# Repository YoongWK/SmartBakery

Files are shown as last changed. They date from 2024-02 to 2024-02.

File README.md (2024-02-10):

# Smart Bakery

The Smart Bakery system is a comprehensive solution for monitoring and controlling temperature and humidity within a bakery. Using a Raspberry Pi Model 3B with a BME280 module, the system publishes data from the bakery to a Flask server via MQTT for storage in an InfluxDB V3.0 Cloud Serverless database. Users can view the bakery data via a Web Dashboard created using HTML, CSS, and JavaScript.

The dashboard also allows users to set temperature thresholds, control heating (Bulb) and cooling (Fan) devices, and activate/deactivate a buzzer alert for extreme temperatures. Moreover, an RGB LED provides a clear visual indication of the current operational status for floor managers in the bakery. Additionally, the system can operate automatically where fan speed and bulb heat levels are adjusted according to the current temperature or manually for direct user control.

By providing real-time environmental tracking and responsive control, the system can maintain optimal conditions in the bakery for high-quality baked goods.

<br />

## Instructions for Raspberry Pi Model 3B Setup
> Step 1: Fabricate the PCB using the gerber files in EAGLE\PCB\SmartBakerySensor

> Step 2: Assemble the PCB

> Step 3: Connect the PCB to the Raspberry Pi Model 3B

> Step 4: Run the Smart_Bakery_Sensor.py Python script in the the Raspberry Pi Model 3B

<br />

## Instructions for Dashboard Setup
> Step 1: Download the app

```bash
git clone https://github.com/YoongWK/SmartBakery.git
cd SmartBakery
```

> Step 2: Enter your MQTT & InfluxDB V3.0 Cloud Serverless details in the .env.example file

> Step 3: Rename the .env.example file to .env

> Step 4: Create the Python virtual environment

```bash
python -m venv .venv
```

> Step 5: Set the execution policy of the current user to unrestricted

```bash
Set-ExecutionPolicy -ExecutionPolicy Unrestricted  -Scope CurrentUser
```

> Step 6: Activate the virtual environment

```bash
.venv\Scripts\activate
```

> Step 7: Install the required libraries into the virtual environment

```bash
pip install -r requirements.txt
```

> Step 8: Run the app

```bash
python app.py
```

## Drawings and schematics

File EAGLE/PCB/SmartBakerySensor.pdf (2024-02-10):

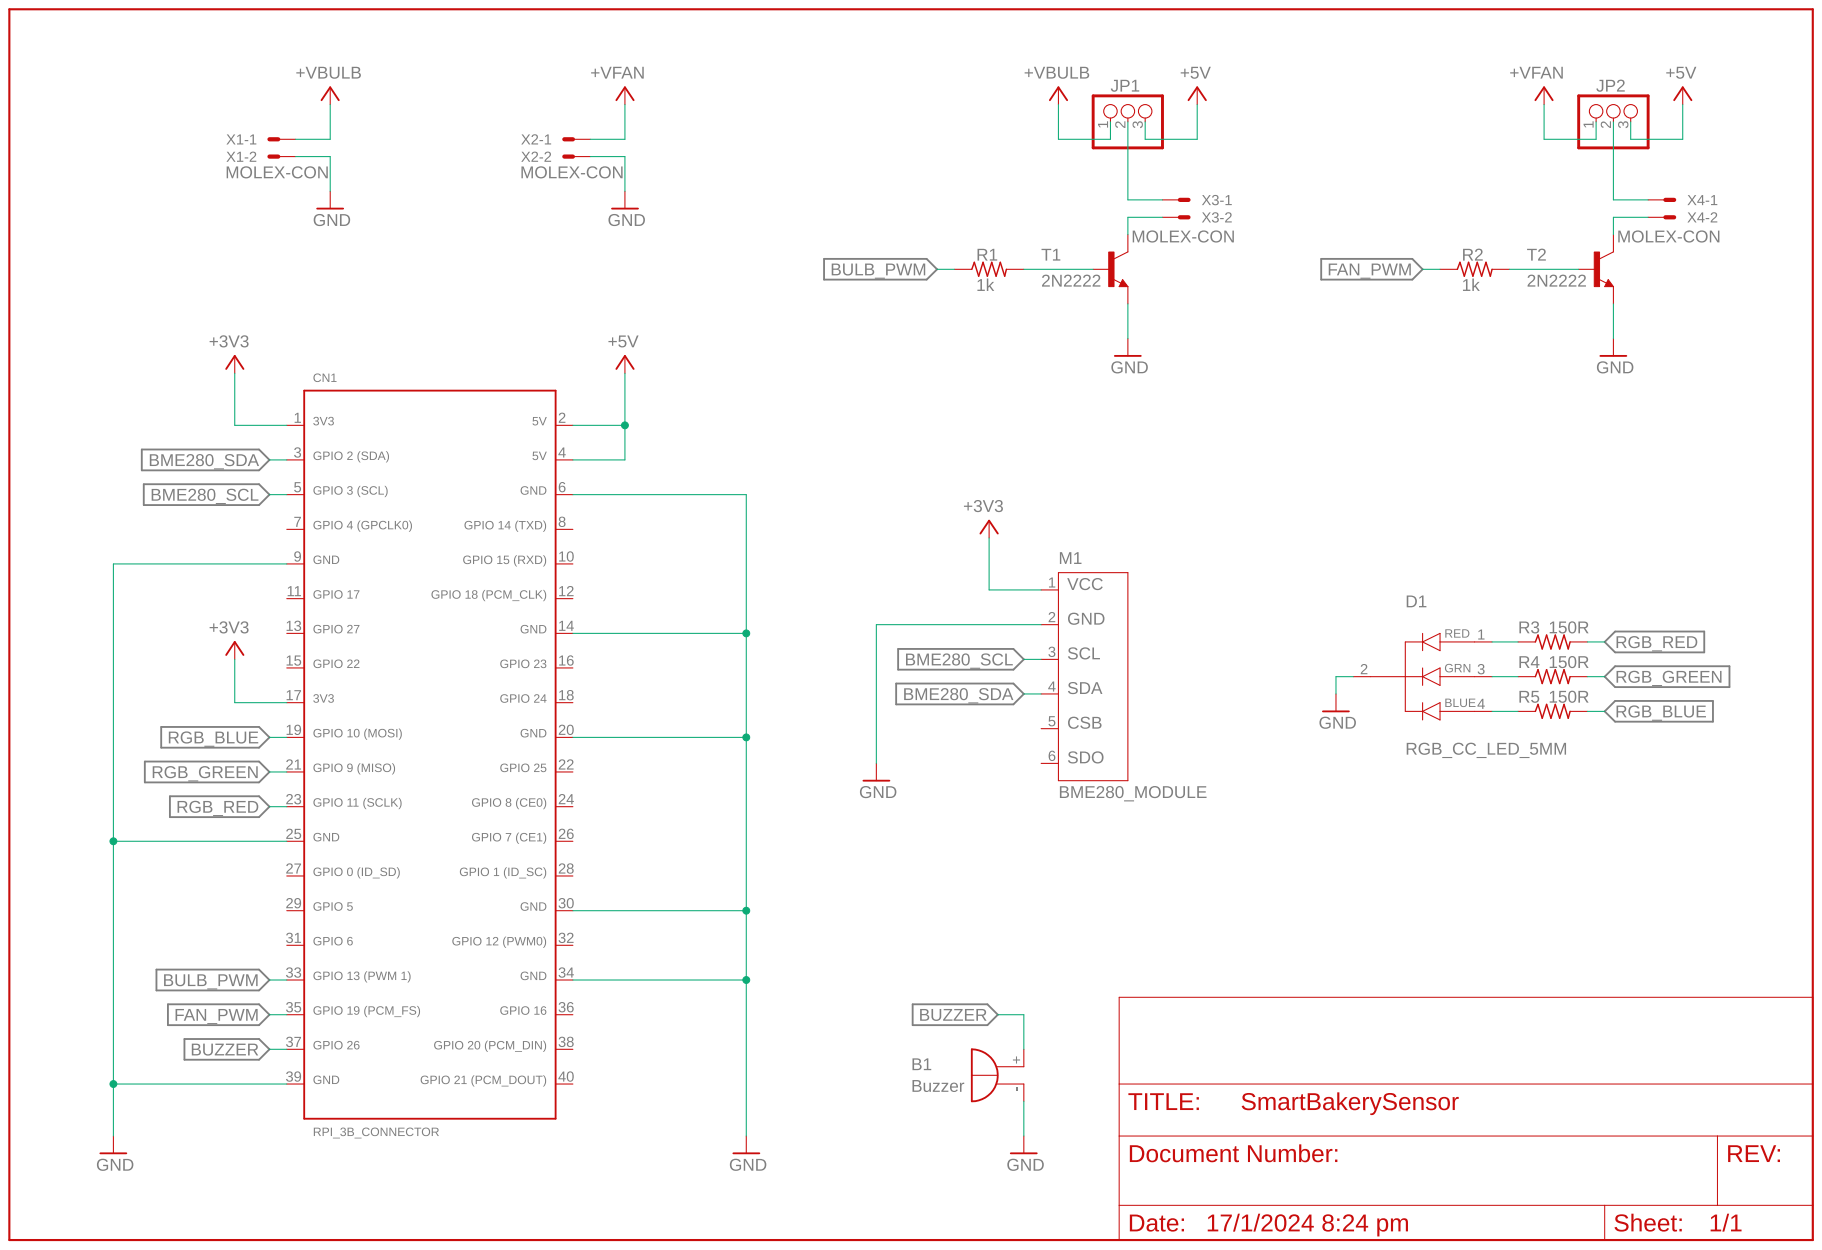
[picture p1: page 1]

SmartBakerySensor BOM
Part Value | Device | Package | Description
B1 Buzzer | F/TMB | F/TMB | BUZZER Source: Buerklin
CN1 RPI_3B_CONNECTOR RPI_3B_CONNECTOR | RPI_3B_CONNECTOR_FOOTPRINT
D1 RGB_CC_LED_5MM RGB_CC_LED_5MM | RGB_CC_LED_FOOTPRINT
JP1 | PINHD-1X3 | 1X03 | PIN HEADER
JP2 | PINHD-1X3 | 1X03 | PIN HEADER
M1 BME280_MODULE | BME280_MODULE | BME280_FOOTPRINT
R1 1k | R-US_R0805 | R0805 | RESISTOR, American symbol
R2 1k | R-US_R0805 | R0805 | RESISTOR, American symbol
R3 150R | R-US_R0805 | R0805 | RESISTOR, American symbol
R4 150R | R-US_R0805 | R0805 | RESISTOR, American symbol
R5 150R | R-US_R0805 | R0805 | RESISTOR, American symbol
T1 2N2222 | 2N2222-NPN-TO92-EBC TO92-EBC | NPN Transistror
T2 2N2222 | 2N2222-NPN-TO92-EBC TO92-EBC | NPN Transistror
X1 MOLEX-CON | 22-23-2021 | 22-23-2021 | .100" (2.54mm) Center Header - 2 Pin
X2 MOLEX-CON | 22-23-2021 | 22-23-2021 | .100" (2.54mm) Center Header - 2 Pin
X3 MOLEX-CON | 22-23-2021 | 22-23-2021 | .100" (2.54mm) Center Header - 2 Pin
X4 MOLEX-CON | 22-23-2021 | 22-23-2021 | .100" (2.54mm) Center Header - 2 Pin

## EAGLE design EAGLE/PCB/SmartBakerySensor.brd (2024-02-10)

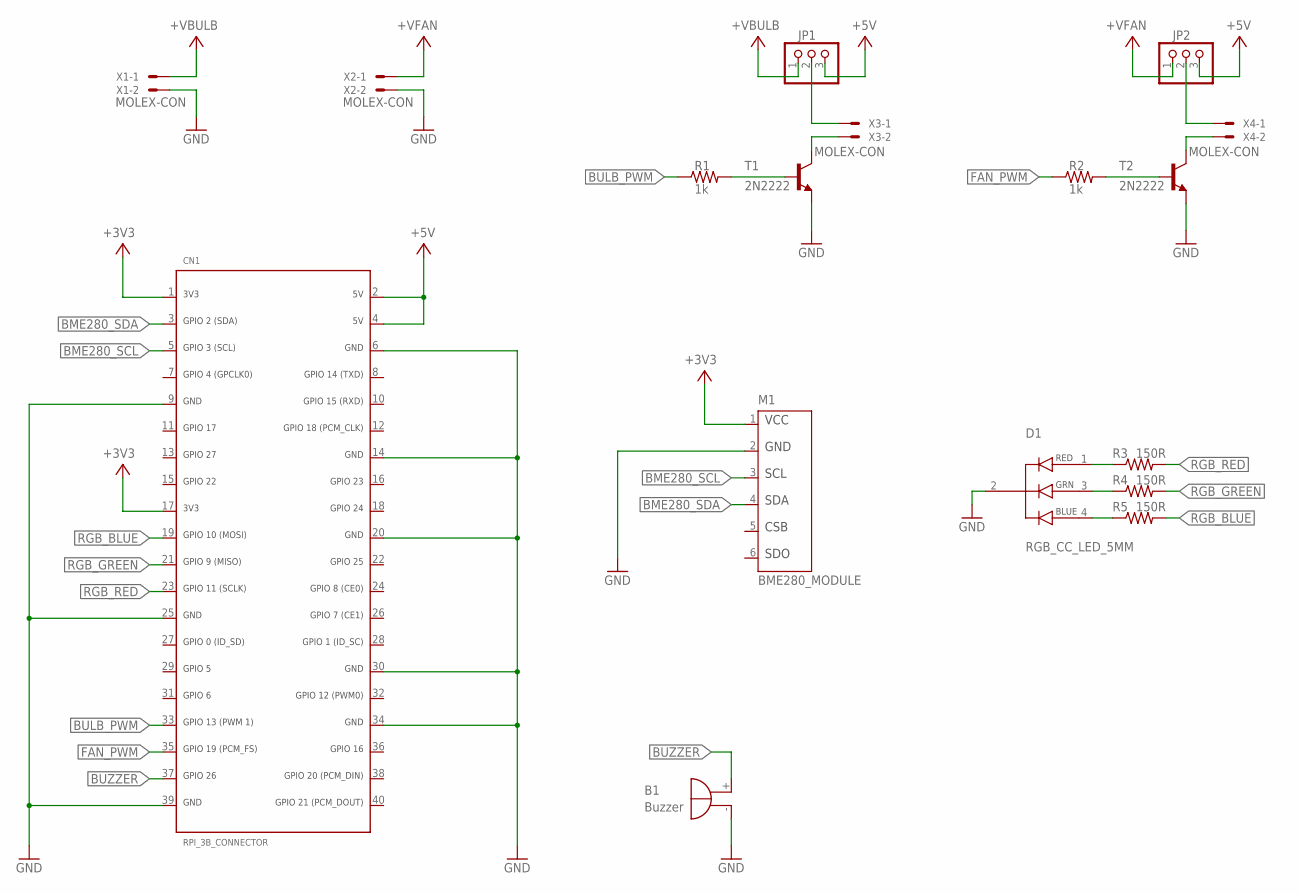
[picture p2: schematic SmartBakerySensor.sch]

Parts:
B1: Buzzer; F/TMB
CN1: RPI_3B_CONNECTOR; RPI_3B_CONNECTOR_FOOTPRINT
D1: RGB_CC_LED_5MM; RGB_CC_LED_FOOTPRINT
JP1, JP2: PINHD-1X3; 1X03
M1: BME280_MODULE; BME280_FOOTPRINT
R1, R2: 1k; R0805
R3, R4, R5: 150R; R0805
T1, T2: 2N2222; TO92-EBC
X1, X2, X3, X4: MOLEX-CON; 22-23-2021

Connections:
+3V3: CN1.1, CN1.17, M1.1
+5V: CN1.2, CN1.4, JP1.3, JP2.3
BME280_SCL: CN1.5, M1.3
BME280_SDA: CN1.3, M1.4
BULB_PWM: CN1.33, R1.1
BUZZER: B1.+, CN1.37
FAN_PWM: CN1.35, R2.1
GND: B1.-, CN1.6, CN1.9, CN1.14, CN1.20, CN1.25, CN1.30, CN1.34, CN1.39, D1.2, M1.2, T1.E, T2.E, X1.2, X2.2
unnamed: D1.1, R3.1
unnamed: D1.3, R4.1
unnamed: D1.4, R5.1
unnamed: R2.2, T2.B
unnamed: R1.2, T1.B
unnamed: T1.C, X3.2
unnamed: T2.C, X4.2
unnamed: JP1.2, X3.1
unnamed: JP2.2, X4.1
RGB_BLUE: CN1.19, R5.2
RGB_GREEN: CN1.21, R4.2
RGB_RED: CN1.23, R3.2
V+: JP2.1, X2.1
VCC: JP1.1, X1.1

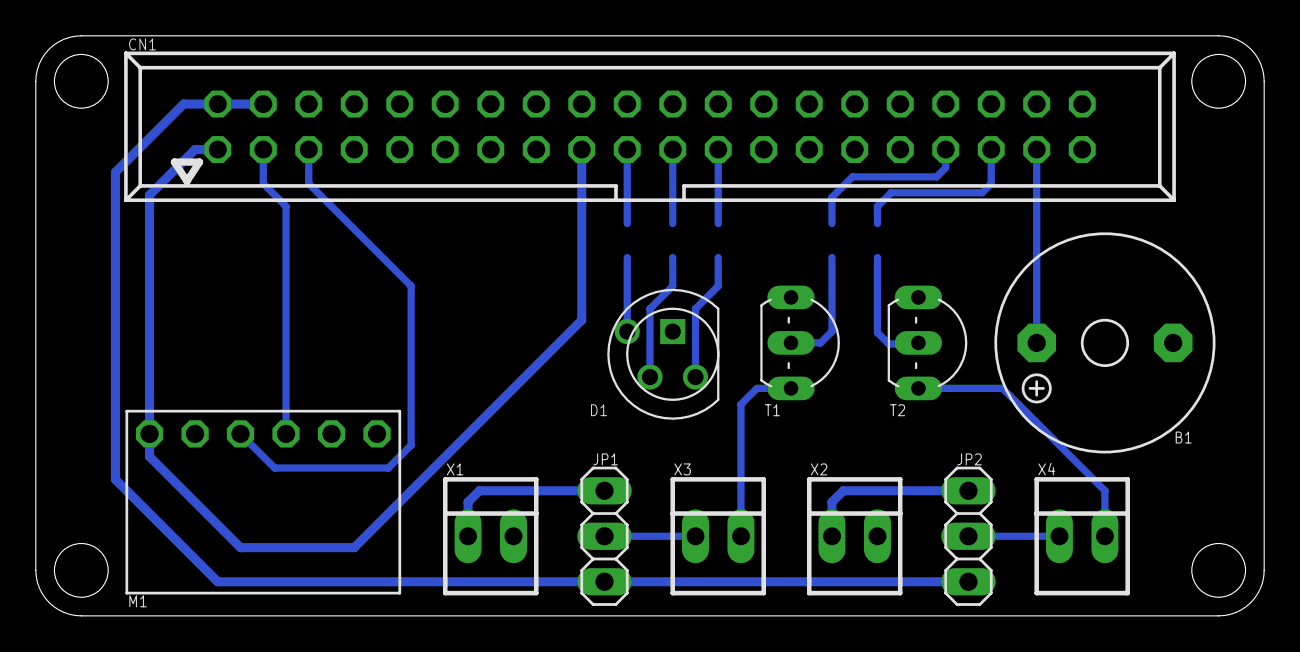
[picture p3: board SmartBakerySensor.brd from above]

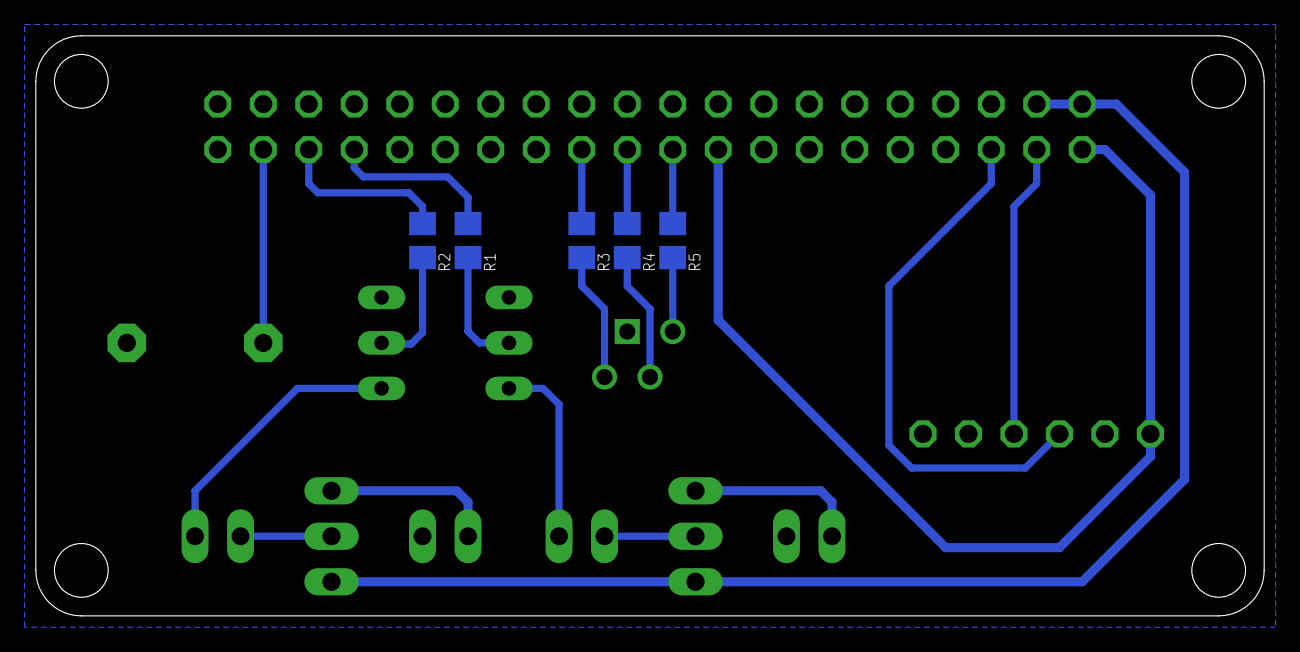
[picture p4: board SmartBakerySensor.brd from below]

Board: 2 copper layers, 68.6 x 32.4 mm, 17 parts (5 on the bottom side), 22 nets.

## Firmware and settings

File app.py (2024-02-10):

#------------------------------------------------------------------- Header Start --------------------------------------------------------------------#
"""
    Project Title: Smart Bakery System
    Project Class: IOTP - PE04
    Project Group: 06
    Project File: app.py
    Project Developers: Andrina Wei Ning Morrison, Ryan Chong Jay Chin, Yoong Wai Kit
    Project Development Period: Nov 2023 - Feb 2024
"""
#-------------------------------------------------------------------- Header End ---------------------------------------------------------------------#

#------------------------------------------------------------------ Imports Start --------------------------------------------------------------------#
import os, certifi, threading, time
from dotenv import load_dotenv
import paho.mqtt.client as mqtt
from datetime import datetime, timedelta
from influxdb_client_3 import InfluxDBClient3, Point, flight_client_options
from flask import Flask, jsonify, request, render_template
#------------------------------------------------------------------- Imports End ---------------------------------------------------------------------#

# Load the .env file containing the InfluxDB V3.0 Cloud Serverless & MQTT Details
load_dotenv(override=True)

#------------------------------------------------------------------ Variables Start ------------------------------------------------------------------#
# Create a Flask Instance
app = Flask(__name__)

# Get the MQTT details from the .env file
mqtt_broker = os.environ.get("MQTT_BROKER")
topic_data = os.environ.get("MQTT_TOPIC_DATA")
topic_control = os.environ.get("MQTT_TOPIC_CONTROL")

# Get the InfluxDB V3.0 Cloud Serverless details from the .env file
token = os.environ.get("INFLUXDB_TOKEN")
host = os.environ.get("INFLUXDB_HOST")
org = os.environ.get("INFLUXDB_ORG")
database = os.environ.get("INFLUXDB_DB")

# Get the TLS root certificate
with open(certifi.where(), "r") as cfile:
    tls_root_certs = cfile.read()

# Create a InfluxDB V3.0 Cloud Serverless Client Instance
dbclient = InfluxDBClient3(host=host,
                           token=token,
                           org=org,
                           database=database,
                           flight_client_options=flight_client_options(tls_root_certs=tls_root_certs))

# Get the latest time
latestdbtime = datetime.now()
#------------------------------------------------------------------- Variables End -------------------------------------------------------------------#

#------------------------------------------------------------------- Routes Start --------------------------------------------------------------------#
# Default route for Flask Web Application dashboard
@app.route("/")
def index():
    return render_template("index.html", url=request.base_url)

# API route to get the latest sensor record from the InfluxDB V3.0 Cloud Serverless database
@app.get('/api/latest-sensor-record')
def get_latest_record():
    global latestdbtime

    # SQL query for the latest sensor record from the InfluxDB V3.0 Cloud Serverless database
    record = dbclient.query(query=f"SELECT * FROM \"data\" ORDER BY time DESC LIMIT 1").to_pandas().iloc[0]
    latestdbtime = record['time']
    latest_record = {"time": record['time'].strftime("%d/%m/%Y - %H:%M:%S"),
                      "temp": float(record['temp']),
                      "hum": float(record['hum']),
                      "fan_speed": int(record['fan_speed']),
                      "bulb_heat": int(record['bulb_heat']),
                      "manual_state": int(record['manual_state']),
                      "buzzer_state": int(record['buzzer_state']),
                      "buzzer_enabled": int(record['buzzer_enabled']),
                      "low_temp": float(record['low_temp']),
                      "high_temp": float(record['high_temp'])}
    return jsonify(latest_record)

# API route to get the latest 5 minutes of sensor record from the InfluxDB V3.0 Cloud Serverless database
@app.get('/api/period-sensor-record')
def get_period_record():
    # SQL query for the latest 5 minutes of sensor record from the InfluxDB V3.0 Cloud Serverless database
    record = dbclient.query(query=f"SELECT * FROM \"data\" WHERE time >= '{latestdbtime - timedelta(minutes=5)}'").to_pandas()

    # Drop columns that are not needed
    record = record.drop(["buzzer_enabled","buzzer_state","high_temp","low_temp","manual_state"], axis = 1)

    # Convert time column to string datatype in "HH:MM:SS" format
    record["time"] = record["time"].dt.strftime("%H:%M:%S").astype(str)
    return record.to_json()

# API route to publish the sensor command to the 'topic_control' MQTT topic
@app.put('/api/sensor-command')
def send_command():
    command = request.json

    # Create the MQTT publisher
    mqtt_publisher = mqtt.Client()
    mqtt_publisher.connect(host=mqtt_broker, port=1883)
    print(f"\nClient was created at {time.strftime('%H:%M:%S')}")

    # Publish the sensor command
    try:
        payload = command['command']
        mqtt_publisher.publish(topic=topic_control, payload=payload, qos=1)
        print(f"Sent command: {payload}")
    
    except Exception as e:
        print(f"Error publishing\n{e}")
    
    else:
        mqtt_publisher.disconnect()
        print("Disconnected from broker\n")
    
    return "Success", 200
#-------------------------------------------------------------------- Routes End ---------------------------------------------------------------------#

#------------------------------------------------------------------ Functions Start ------------------------------------------------------------------#
# Function to write data to the InfluxDB V3.0 Cloud Serverless database based on the sensor data from the RPI
def onMessage(client, userdata, message):
    time, temp, hum, fan_speed, bulb_heat, manual_state, buzzer_state, buzzer_enabled, low_temp, high_temp = message.payload.decode('utf-8').split(',')
    record = (Point("data")
              .time(time)
              .field("temp", float(temp))
              .field("hum", float(hum))
              .field("fan_speed", int(fan_speed))
              .field("bulb_heat", int(bulb_heat))
              .field("manual_state", int(manual_state))
              .field("buzzer_state", int(buzzer_state))
              .field("buzzer_enabled", int(buzzer_enabled))
              .field("low_temp", float(low_temp))
              .field("high_temp", float(high_temp)))
    dbclient.write(record=record)

# Function to start the MQTT subscriber for sensor data from the 'topic_data' topic
def startMQTT():
    mqtt_subscriber = mqtt.Client()
    mqtt_subscriber.on_message = onMessage
    mqtt_subscriber.connect(host=mqtt_broker, port=1883)
    mqtt_subscriber.subscribe(topic=topic_data, qos=1)
    mqtt_subscriber.loop_start()
#------------------------------------------------------------------- Functions End -------------------------------------------------------------------#

#---------------------------------------------------------------- Main Program Start -----------------------------------------------------------------#
if __name__ == "__main__":
    # Start the MQTT subscriber thread for the 'topic_data' topic
    subscriberThread = threading.Thread(target=startMQTT)
    subscriberThread.start()

    # Run the app
    app.run(host='0.0.0.0', port=5000, debug=True)
#----------------------------------------------------------------- Main Program End ------------------------------------------------------------------#

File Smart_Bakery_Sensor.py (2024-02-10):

#-------------------------------------------- Header Start ---------------------------------------------#
"""
    Project Title: Smart Bakery System
    Project Class: IOTP - PE04
    Project Group: 06
    Project File: Smart_Bakery_Sensor.py
    Project Developers: Andrina Wei Ning Morrison, Ryan Chong Jay Chin, Yoong Wai Kit
    Project Development Period: Nov 2023 - Feb 2024
"""
#--------------------------------------------- Header End ----------------------------------------------#

#-------------------------------------------- Imports Start --------------------------------------------#
import time
import threading
from datetime import datetime
import RPi.GPIO as GPIO
import paho.mqtt.client as mqtt
import smbus2
import bme280
#--------------------------------------------- Imports End ---------------------------------------------#

#------------------------------------- RPI Pin Configuration Start -------------------------------------#
# RPI GPIO PIN Assignment
RED_LED_PIN = 11
GREEN_LED_PIN = 9
BLUE_LED_PIN = 10
BULB_PWM_PIN = 13
FAN_PWM_PIN = 19
BUZZER_PIN = 26

# RPI GPIO PIN Setting
GPIO.setmode(GPIO.BCM)
GPIO.setup(RED_LED_PIN, GPIO.OUT)
GPIO.setup(GREEN_LED_PIN, GPIO.OUT)
GPIO.setup(BLUE_LED_PIN, GPIO.OUT)
GPIO.setup(BULB_PWM_PIN, GPIO.OUT)
GPIO.setup(FAN_PWM_PIN, GPIO.OUT)
GPIO.setup(BUZZER_PIN, GPIO.OUT)
BULB = GPIO.PWM(BULB_PWM_PIN, 100)
FAN = GPIO.PWM(FAN_PWM_PIN, 100)
#-------------------------------------- RPI Pin Configuration End --------------------------------------#

#------------------------------------------- Variables Start -------------------------------------------#
# Program Variable
run_program = True

# MQTT Variables
mqtt_broker = 'test.mosquitto.org'
topic_data = 'iotp/proj/grp06/sensordata'
topic_control = 'iotp/proj/grp06/sensorcontrol'

# BME280 Variables
bus = smbus2.SMBus(bus=1)
address = 0x76
calibration_params = bme280.load_calibration_params(bus=bus, address=address)

# Smart Bakery Variables
low_temp = 27
high_temp = 29
rgb_color = ""
fan_speed = 0
bulb_heat = 0
buzzer_enabled = 1
buzzer_state = 0
manual_state = 0
#-------------------------------------------- Variables End --------------------------------------------#

#------------------------------------------- Functions Start -------------------------------------------#
# Function to set the RGB LED color
def setRGBLEDColor(color):
    if color == "blue":
        GPIO.output(RED_LED_PIN, GPIO.LOW) # Red low
        GPIO.output(GREEN_LED_PIN, GPIO.LOW) # Green low
        GPIO.output(BLUE_LED_PIN, GPIO.HIGH) # Blue high
    elif color == "green":
        GPIO.output(RED_LED_PIN, GPIO.LOW) # Red low
        GPIO.output(GREEN_LED_PIN, GPIO.HIGH) # Green high
        GPIO.output(BLUE_LED_PIN, GPIO.LOW) # Blue low
    elif color == "red":
        GPIO.output(RED_LED_PIN, GPIO.HIGH) # Red high
        GPIO.output(GREEN_LED_PIN, GPIO.LOW) # Green low
        GPIO.output(BLUE_LED_PIN, GPIO.LOW) # Blue low
    else:
        GPIO.output(RED_LED_PIN, GPIO.LOW) # Red low
        GPIO.output(GREEN_LED_PIN, GPIO.LOW) # Green low
        GPIO.output(BLUE_LED_PIN, GPIO.LOW) # Blue low

# Function to calculate the PWM level
def calculateLevel(value, max_level, step):
    return min(int(value // step) + 1, max_level)

# Function to set the bulb heat via PWM
def setBulbHeat(heat, max_level):
    BULB.ChangeDutyCycle(max(min(heat * (100 / max_level), 100), 0))

# Function to set the fan speed via PWM
def setFanSpeed(speed, max_level):
    FAN.ChangeDutyCycle(max(min(speed * (100 / max_level), 100), 0))

# Function to set the buzzer state
def setBuzzerState(state):
    GPIO.output(BUZZER_PIN, GPIO.LOW if (state == 0) else GPIO.HIGH)

# Function to set the control variables value according to the commands received
def onMessage(client, userdata, message):
    global manual_state, fan_speed, bulb_heat, buzzer_enabled, low_temp, high_temp
    payload = message.payload.decode('utf-8')
    print(f"\nReceived command: {payload}")
    
    if "manualstate" in payload:
        manual_state = int(payload.split(',')[1])
    elif "fanspeed" in payload:
        fan_speed = int(payload.split(',')[1])
    elif "bulbheat" in payload:
        bulb_heat = int(payload.split(',')[1])
    elif "buzzerenabled" in payload:
        buzzer_enabled = int(payload.split(',')[1])
    elif "lowtemp" in payload:
        low_temp = float(payload.split(',')[1])
    elif "hightemp" in payload:
        high_temp = float(payload.split(',')[1])

# Function to start the MQTT subscriber for sensor commands from the 'topic_control' topic
def startMQTTSubscriber():
    mqtt_subscriber = mqtt.Client()
    mqtt_subscriber.on_message = onMessage
    mqtt_subscriber.connect(host=mqtt_broker, port=1883)
    mqtt_subscriber.subscribe(topic=topic_control, qos=1)
    mqtt_subscriber.loop_start()

# Function to start the MQTT publisher for sensor data to the 'topic_data' topic & update the device variables
def startMQTTPublisher():
    global rgb_color, fan_speed, bulb_heat, buzzer_state
    
    while run_program:
        date_time = datetime.now()
        data = bme280.sample(bus=bus, address=address, compensation_params=calibration_params)
        
        # Set the device variables according to the latest temperature readings
        if data.temperature >= high_temp:
            rgb_color = "red"
            if manual_state == 0:
                fan_speed = calculateLevel(value=(data.temperature - high_temp), max_level=5, step=0.5)
                bulb_heat = 0
            buzzer_state = 1
        elif data.temperature < low_temp:
            rgb_color = "blue"
            if manual_state == 0:
                fan_speed = 0
                bulb_heat = calculateLevel(value=(low_temp - data.temperature), max_level=5, step=0.5)
            buzzer_state = 1
        else:
            rgb_color = "green"
            if manual_state == 0:
                fan_speed = 0
                bulb_heat = 0
            buzzer_state = 0
        
        # Create the MQTT publisher
        mqtt_publisher = mqtt.Client()
        mqtt_publisher.connect(host=mqtt_broker, port=1883)
        print(f"\nClient was created at {date_time.strftime('%H:%M:%S')}")
        
        # Publish the sensor data
        try:
            payload = f"{date_time},{data.temperature:.02f},{data.humidity:.02f},{fan_speed},{bulb_heat},{manual_state},{buzzer_state},{buzzer_enabled},{low_temp:.01f},{high_temp:.01f}"
            mqtt_publisher.publish(topic=topic_data, payload=payload, qos=1)
            print(f"Sent record: {payload}")
        except Exception as e:
            print(f"Error publishing\n{e}")
        else:
            mqtt_publisher.disconnect()
            print("Disconnected from broker")
        
        time.sleep(1)
#-------------------------------------------- Functions End --------------------------------------------#
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

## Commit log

2024-01-22 Added Temperature, Humidity, Bulb Heat, & Fan Speed Time Series Graph.
2024-02-10 Commented code and added EAGLE PCB files.
    [SmartBakerySensor.brd, SmartBakerySensor.sch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]
